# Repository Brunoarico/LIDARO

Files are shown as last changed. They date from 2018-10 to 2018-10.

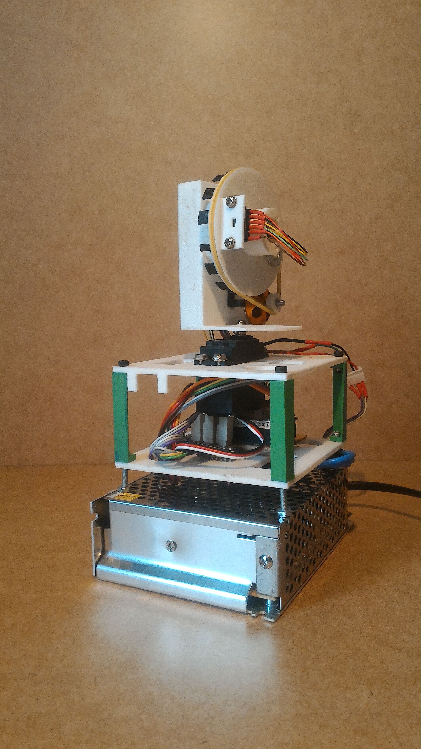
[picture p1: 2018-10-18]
imagens/P_20180928_121911_1_p.jpg

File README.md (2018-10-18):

# Introdução

Este trabalho tem por ideia principal desenvolver um sensor para o imageamento de ambientes denominado Lidar (Light Detection and Ranging), de forma que ele seja flexível em sua aplicação. Neste processo de desenvolvimento serão explorados temas de computação embarcada, microcontroladores, coleta de dados por meio de sensores e o tratamento desses dados.
O processo também envolverá uma forma de como extrair características úteis desse conjunto de dados para que seja aplicada principalmente na área de veículos autônomos.

# Motivação

Na área de veículos autônomos e robótica móvel, a necessidade de se conhecer o ambiente em que o móvel se encontra torna-se imprescindível. Para isso utiliza-se diversas técnicas de visão compotacional tentando otimizar, de alguma forma, a quantidade de dados coletado do ambiente unido a maior eficiência computacional para fazer isso.
Partindo dessa premissa, o LidaR tem se tornado um sensor muito utilizado por suprir exatamente esses requisitos, o que foi possível graças, essencialmente, ao aumento de poder computacional dos embarcado e a diminuição dos custos de fabricação dos circuitos integrados.
Existem diversas tecnologias diferentes para a implementtação de LiDaR's desde utilizando espelhos móveis, alternativas utilizando CCD's lineares e também construções híbridas, assim tendo este TCC também o foco de estudo de uma implementação que pondere tanto as questões de custo de implementação como de eficiência computacional.

# Objetivos 

O objetivo deste trabalho é de construir um Lidar, um sensor que utiliza um laser para medir distâncias e fazer um mapeamento do ambiente no qual se encontra imerso. 
A construção envolverá desde a construção do hardware, o firmware que operará esse hardware, até o software que fará o tratamento da nuvem de pontos gerada. 
A estrutura do Lidar em sí tambem envolverá a modelagem 3D das peças para que sejam prototipadas usando ferramentas de fabricação digital, como cortadora Laser e impressoras 3D.

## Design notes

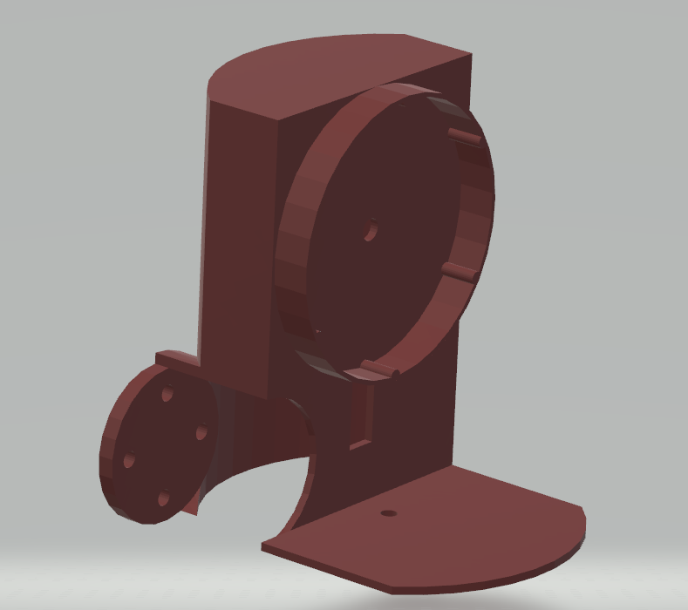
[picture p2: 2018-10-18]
imagens/Lidar3.png

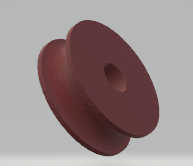
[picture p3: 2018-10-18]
imagens/Polia.png

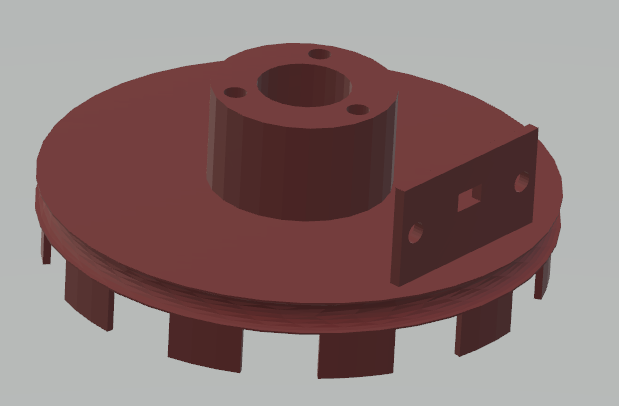
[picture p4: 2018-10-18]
imagens/rotor3.png

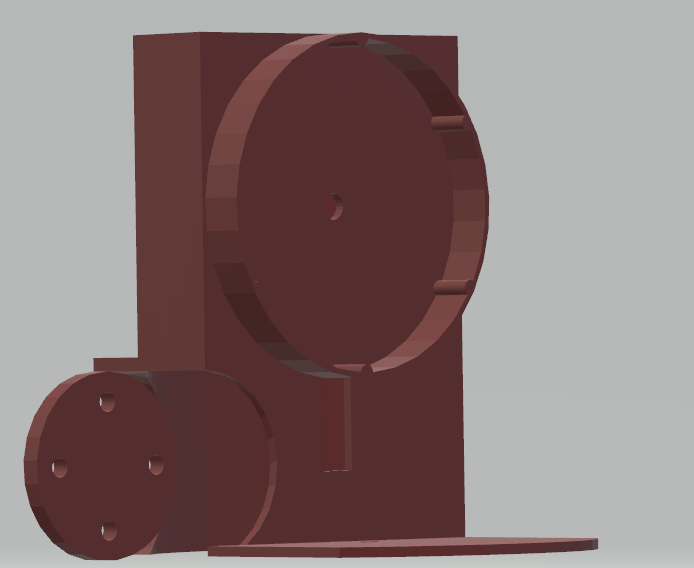
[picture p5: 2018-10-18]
imagens/Lidar2.png

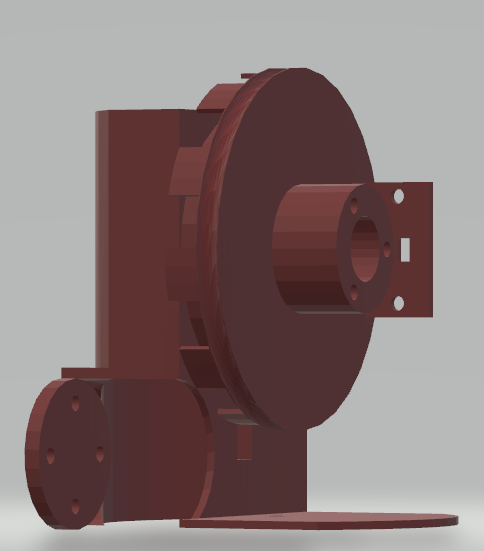
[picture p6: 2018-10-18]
imagens/montado2.png

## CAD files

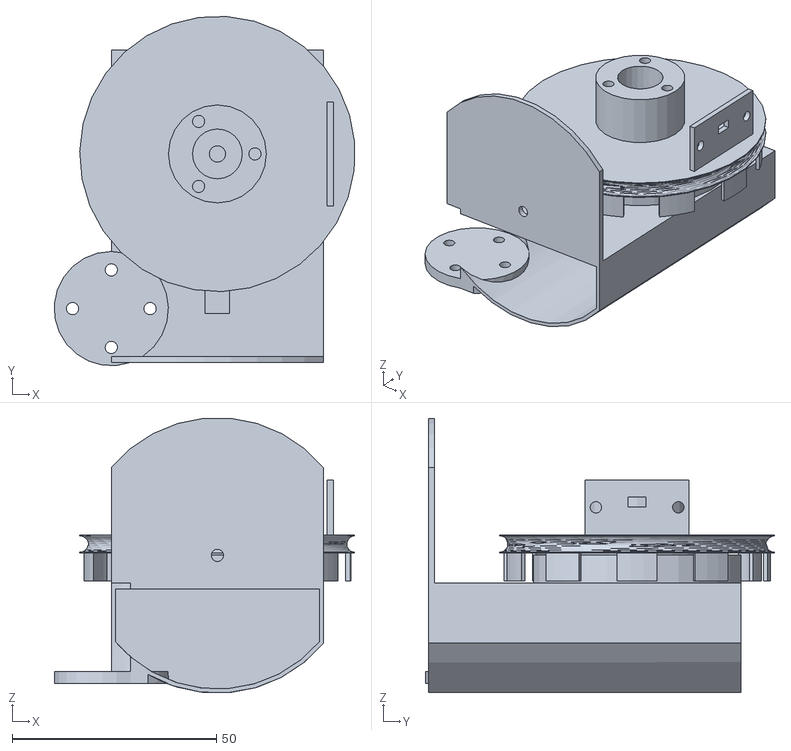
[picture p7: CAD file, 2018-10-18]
structures/Assembled.stl
73.6 x 85.5 x 67.2

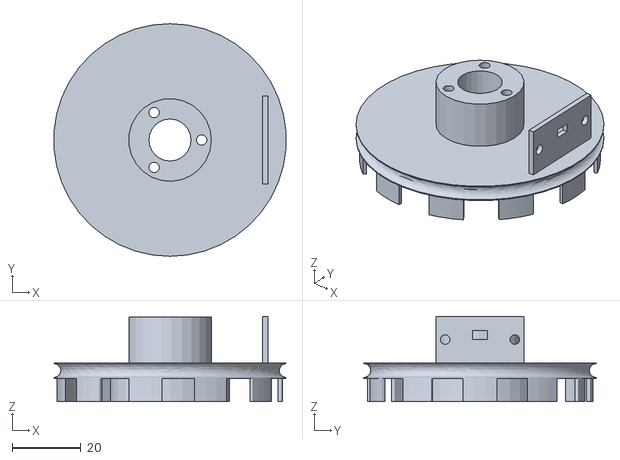
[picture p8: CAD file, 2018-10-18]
structures/Rotor_D_complete.stl
67.3 x 67.5 x 24.8

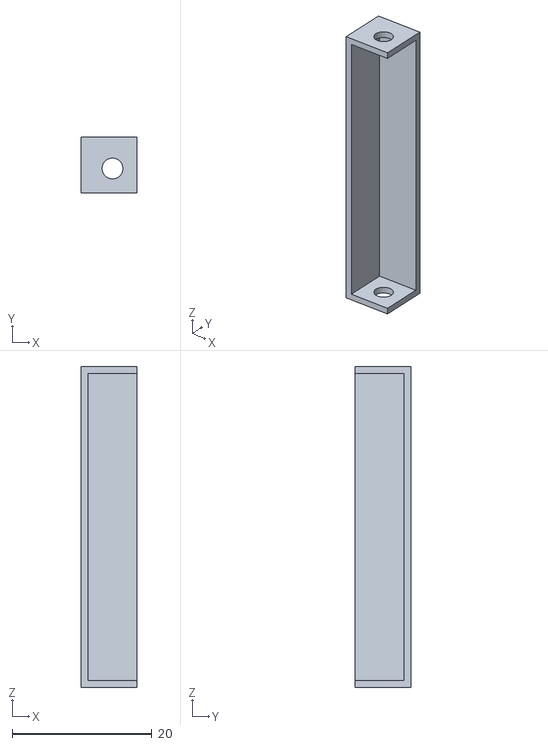
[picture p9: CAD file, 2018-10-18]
structures/coluna.stl
8.00 x 8.00 x 46.0

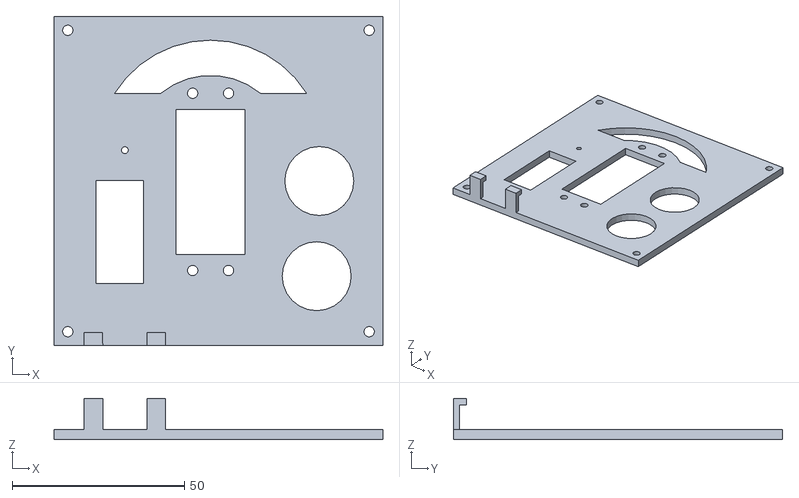
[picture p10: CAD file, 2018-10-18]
structures/teto.stl
95.4 x 95.4 x 12.0

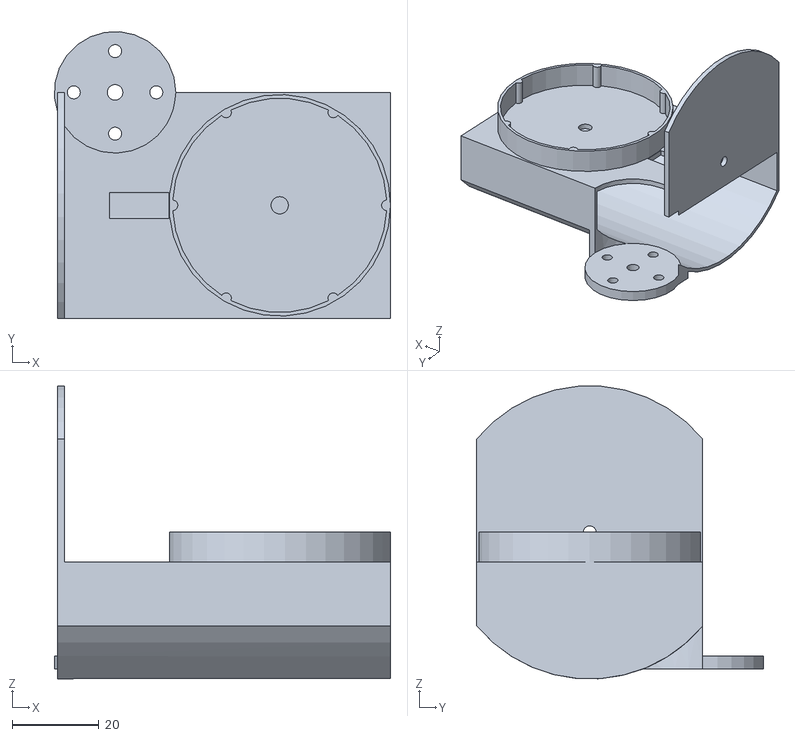
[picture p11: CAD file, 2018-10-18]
structures/body_S_brushless.stl
77.3 x 66.0 x 67.3

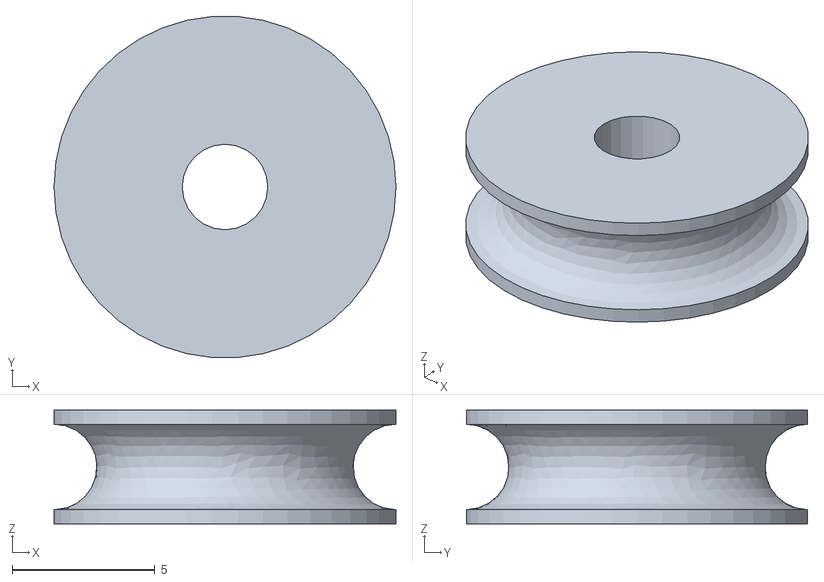
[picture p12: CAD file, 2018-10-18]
structures/polia.stl
12.0 x 12.0 x 4.00

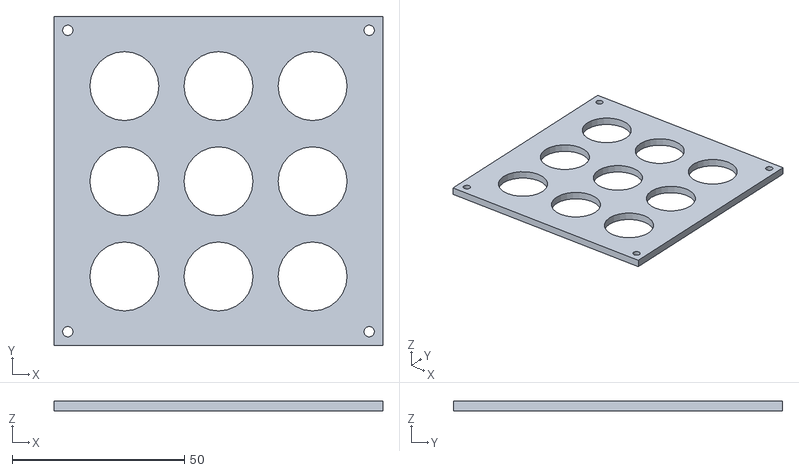
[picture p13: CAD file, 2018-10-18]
structures/chao.stl
95.4 x 95.4 x 3.00

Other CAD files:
structures/Assembled.dwg
structures/Rotor_D_complete.dwg
structures/body_S_brushless.dwg
structures/chao.dwg
structures/coluna.dwg
structures/polia.dwg
structures/teto.dwg

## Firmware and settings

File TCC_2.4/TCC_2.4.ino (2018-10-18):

#include <Servo.h>
#include <VL53L0X.h>
#include <Wire.h>
#include <WiFi.h>
#include <ArduinoOTA.h> 
#include <ESPmDNS.h> 
#include <DNSServer.h>
#include <WebServer.h>
#include <WiFiManager.h> 
#include <WiFiUdp.h> 
#include "MPU6050_6Axis_MotionApps20.h"

#define MOT_PIN 25
#define SERV_LIDAR 21
#define ENC_PIN 14
#define deg 12.0
#define OUT_OF_RANGE 8190
#define uS_MIN  550
#define uS_MAX  2000
#define DEL_uS 10

#define MPU6050_ACCEL_OFFSET_X -574
#define MPU6050_ACCEL_OFFSET_Y 1050
#define MPU6050_ACCEL_OFFSET_Z 1210
#define MPU6050_GYRO_OFFSET_X  -21
#define MPU6050_GYRO_OFFSET_Y  -22
#define MPU6050_GYRO_OFFSET_Z  47


static int taskCore = 0;

const char* ssid = "TARDIS";
const char* password =  "PraiaPeruibe";
const uint16_t port = 8090;
const int udpPort = 8091;
char host[14] = "192.168.0.115";
WiFiManagerParameter ip_server("ip_server", "ip server", host, 14);
Servo motor;
Servo servo_lidar;
VL53L0X sensor;
WiFiClient client;
WiFiUDP udp;
MPU6050 mpu;

volatile unsigned long int last_t = 0;
volatile double del = 0;
volatile int angle_real_alt = 0, angle_estimate_alt = 0;
volatile int value = 0;
volatile unsigned long int last_volta = 0;

String data_s;
int sensor_read;
int last;

// MPU control/status vars
bool dmpReady = false;  // set true if DMP init was successful
uint8_t mpuIntStatus;   // holds actual interrupt status byte from MPU
uint8_t devStatus;      // return status after each device operation (0 = success, !0 = error)
uint16_t packetSize;    // expected DMP packet size (default is 42 bytes)
uint16_t fifoCount;     // count of all bytes currently in FIFO
uint8_t fifoBuffer[64]; // FIFO storage buffer

// orientation/motion vars
Quaternion q;           // [w, x, y, z]         quaternion container
VectorFloat gravity;    // [x, y, z]            gravity vector
float ypr[3];           // [yaw, pitch, roll]   yaw/pitch/roll container and gravity vector

int us = uS_MIN;
int incr_us = DEL_uS;
int inc = DEL_uS;
int angle_az = 0;
int angle_max = 180;
int angle_min = 0;
unsigned long int last_osc = 0;

int offset_az = 0;
int offset_alt = 195;

int osc_t = 90;
int vel_e = 25;
bool onoff = false;

uint8_t buffer[50] = "";

hw_timer_t * timer = NULL;

int vel_mode_az[]  = {0,400,300,200,100};
int vel_mode_alt[] = {25, 49, 50, 51, 52};

void initialize_MPU() {
  mpu.initialize();
  devStatus = mpu.dmpInitialize();

    // supply your own gyro offsets here, scaled for min sensitivity
  mpu.setXAccelOffset(MPU6050_ACCEL_OFFSET_X);
  mpu.setYAccelOffset(MPU6050_ACCEL_OFFSET_Y);
  mpu.setZAccelOffset(MPU6050_ACCEL_OFFSET_Z);
  mpu.setXGyroOffset(MPU6050_GYRO_OFFSET_X);
  mpu.setYGyroOffset(MPU6050_GYRO_OFFSET_Y);
  mpu.setZGyroOffset(MPU6050_GYRO_OFFSET_Z);
  if (devStatus == 0) {
        mpu.setDMPEnabled(true);
        mpuIntStatus = mpu.getIntStatus();
        dmpReady = true;
        packetSize = mpu.dmpGetFIFOPacketSize();
    } 

}

void IRAM_ATTR estimation() {
  angle_estimate_alt++;
  angle_estimate_alt = angle_estimate_alt % 360;
}

void wifi_setup() {
  WiFiManager wifiManager;
  wifiManager.addParameter(&ip_server);
  wifiManager.autoConnect("LIDARO_CONF");
  strcpy(host, ip_server.getValue());
  udp.begin(udpPort);
  Serial.print("WiFi connected with IP: ");
  Serial.println(WiFi.localIP());
}

void OTA_setup() {
  ArduinoOTA.setHostname("LIDAR");
  ArduinoOTA.begin();
}

void wifi_send(String data_stream) {
    if (client.connect(host, port)) {
      client.print(data_stream);
    }
    client.stop();
}

void setup_timer() {
  timer = timerBegin(3, 80, true);
  timerAttachInterrupt(timer, &estimation, true);
  timerAlarmWrite(timer, 1000000, true);
  timerAlarmEnable(timer);
}


void oscillating_radar(int next){
  if(next > 0 && millis() - last_osc > next) {
    angle_az = map(us, uS_MIN, uS_MAX, angle_min, angle_max);
    if(angle_az >= 180 && inc > 0){
      inc = -incr_us;
    }
    else if(angle_az <= 0 && inc < 0) {
      inc = incr_us;
    }
    if(inc > 0) angle_az -= offset_az;
    us += inc;
    servo_lidar.writeMicroseconds(us);
    last_osc = millis();
  }
}

void get_inclination () {
  if (!dmpReady) return;
  mpuIntStatus = mpu.getIntStatus();
  // get current FIFO count
  fifoCount = mpu.getFIFOCount();
  Serial.println(fifoCount);
  // check for overflow (this should never happen unless our code is too inefficient)
  if ((mpuIntStatus & 0x10) || fifoCount == 1024) {
        mpu.resetFIFO();
        Serial.println(F("FIFO overflow!"));
  } 
  else if (mpuIntStatus & 0x02) {
        // wait for correct available data length, should be a VERY short wait
        while (fifoCount < packetSize) fifoCount = mpu.getFIFOCount();

        mpu.getFIFOBytes(fifoBuffer, packetSize);
        
        fifoCount -= packetSize;

        mpu.dmpGetQuaternion(&q, fifoBuffer);
        mpu.dmpGetGravity(&gravity, &q);
        mpu.dmpGetYawPitchRoll(ypr, &q, &gravity);
        ypr[0] *= 180/M_PI;
        ypr[1] *= 180/M_PI;
        ypr[2] *= 180/M_PI;  
  }  
}

/*void update_state(String cmd) {
  char opt = cmd.charAt(0);
  int value =  cmd.substring(1).toInt();
  Serial.println(String(opt) + " " + String(value));
  if(opt == 'a') {osc_t = value;}
  else if (opt == 'e'){motor.write(value/10);}
  else if (opt == 'o') {
    if(value) {
      unsigned long int n = millis();
      while(millis()-n < 50) get_inclination();
      wifi_send("c0 " + String(ypr[0])+ " " +String(ypr[1]) + " "+ String(ypr[2]));
      Serial.println("send cal " + String(ypr[0])+ " " +String(ypr[1]) + " "+ String(ypr[2]));
      delay(100);
    }
    onoff = value;
  }
}*/

void update_state(String cmd) {
  char opt = cmd.charAt(0);
  int value =  cmd.substring(1).toInt();
  Serial.println(String(opt) + " " + String(value));
  if(opt == 'a') osc_t = vel_mode_az[value];
  else if (opt == 'e') motor.write(vel_mode_alt[value]);
  else if (opt == 'o') {
    if(value) {
      unsigned long int n = millis();
      while(millis()-n < 50) get_inclination();
      wifi_send("c0 " + String(ypr[0])+ " " +String(ypr[1]) + " "+ String(ypr[2]));
      Serial.println("send cal " + String(ypr[0])+ " " +String(ypr[1]) + " "+ String(ypr[2]));
      delay(100);
    }
    onoff = value;
  }
}

void read_command () {
  if(udp.parsePacket() > 0){
    udp.read(buffer, 50);
    //Serial.print("Server to client: ");
    //Serial.println((char *)buffer);
    update_state((char *)buffer);
  }
}

void setup_sensor() {
  Wire.begin(5, 4);
  sensor.init();
  sensor.setTimeout(500);
  sensor.startContinuous();
  sensor.setMeasurementTimingBudget(20000);
}

void IRAM_ATTR timming () {
  unsigned long int now_t = millis();
  double tmp = now_t - last_t;
  if (tmp > 0) {
    if(del/tmp < 0.5 && angle_real_alt > 300) {
      angle_real_alt = 0;
    }
    del = tmp;
    last_t = now_t;
    angle_real_alt += deg;
    timerAlarmWrite(timer, del*1000.0/deg, true);
    angle_estimate_alt = angle_real_alt - offset_alt;
  }
}

void setup() {
  Serial.begin(115200);
  motor.attach(MOT_PIN);
  motor.write(25);
  servo_lidar.attach(SERV_LIDAR);
  setup_sensor();
  attachInterrupt(digitalPinToInterrupt(ENC_PIN), timming, CHANGE); 
  delay(1000);
  Serial.println("conectando");
  wifi_setup();
  Serial.println("conectado");
  OTA_setup();
  Serial.println("configurado");
  setup_timer();
  initialize_MPU();
  memset(buffer, 0, 50);
  xTaskCreatePinnedToCore(
                    coreTask,   
                    "coreTask", 
                    10000,      
                    NULL,       
                    0,          
                    NULL,       
                    taskCore);  
}


void coreTask( void * pvParameters ){
    String taskMessage = "Task running on core ";
    taskMessage = taskMessage + xPortGetCoreID();
    while(true){
      if(onoff){
        wifi_send(data_s);
        Serial.println(data_s);
        delay(10);
      }
      else{
        wifi_send("ping");
        delay(500);
      }
    }
}

void loop() {
  ArduinoOTA.handle();
  read_command();
  //Serial.println(String(vel_e) + " " + String(osc_t) + " " + String(onoff));
  if(onoff){
    sensor_read = sensor.readRangeSingleMillimeters();
    if(sensor_read < OUT_OF_RANGE) data_s = String(angle_estimate_alt) + " " + String(angle_az) + " " + String(sensor_read);
    else data_s = String(angle_estimate_alt) + " " + String(angle_az) + " " + String(-1);
    oscillating_radar(osc_t);
    //Serial.println(data_s +" "+ String(millis()-last));
    last = millis();
  }
}

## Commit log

2018-10-18 adicionando versao 2.4
    [caixa.csv, caixa2.csv, caixa3.csv]
2018-10-18 add structures
    [Assembled.dwg, Assembled.stl, Rotor_D_complete.dwg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]
